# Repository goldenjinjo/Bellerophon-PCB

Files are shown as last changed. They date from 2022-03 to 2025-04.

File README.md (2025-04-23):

# hardware
Pronounced: BE-LLER-O-FIN

Pyro-capable Flight Computer with a pressure sensor and IMU. Designed to be general purpose and small enough to fit inside any rocket. Originally developed for UNSW Rocketry Team. 

**PARTS LIST:**

- Microprocessor: Teensy 4
- Barometer/Altimeter: MPL3115A2
- Inertial Measurement Unit (IMU): LSM6DS3
- Memory: XTSD 4GB NAND Flash
- Secondary IMU (optional): Adafruit ICM20948 Breakout Board
- PWM Buzzer
- Individual R, G, B Leds + dedicated programmable LEDs for Barometer, IMU and Flash

---

## 📸 Overview

### 📐 PCB Layout

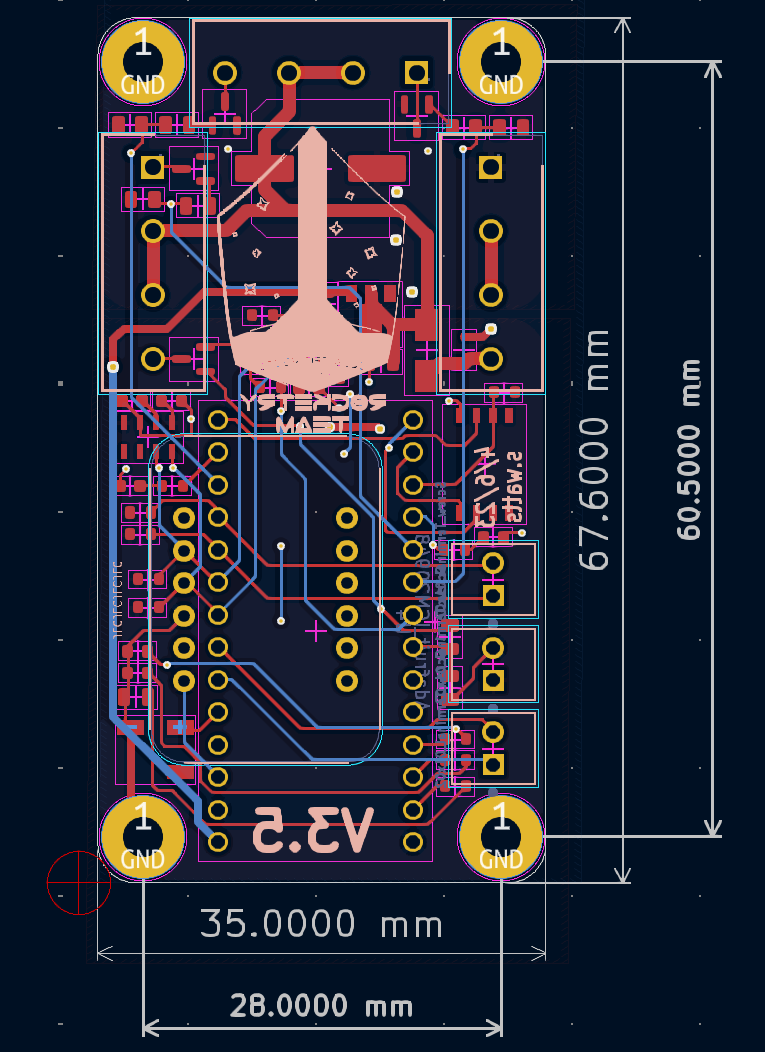
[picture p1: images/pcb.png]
PCB Layout


**Dimensions**: 35.0 mm × 67.6 mm  
**Mounting Holes**: ⌀3.2 mm (4-cornered)

---

### 🔧 Render – Back Side (Component View)

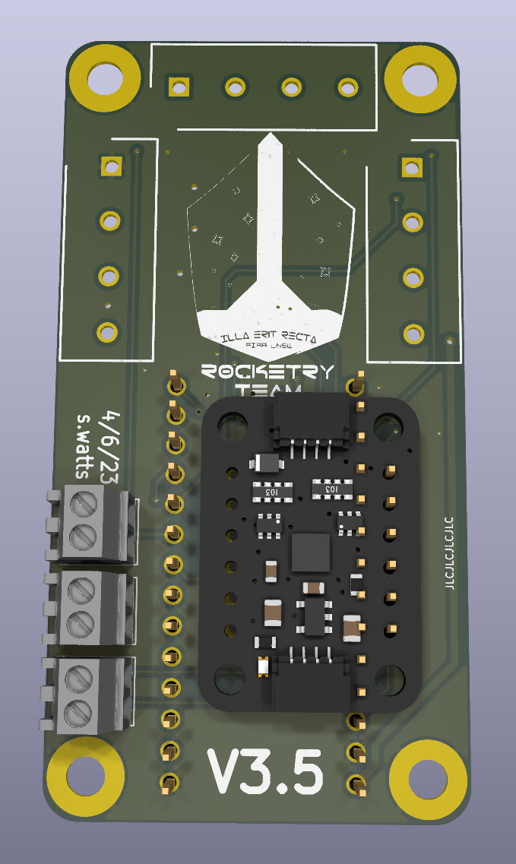
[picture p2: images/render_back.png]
Back Render


---

### ⚙️ Render – Front Side (Sensor & Output Side)

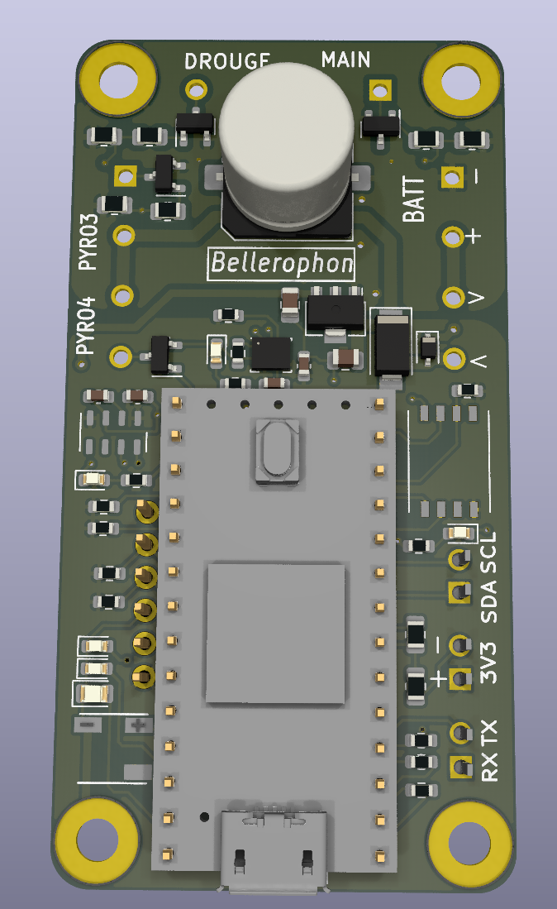
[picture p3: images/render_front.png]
Front Render


---

## 📊 Schematic

Schematic

Includes overcurrent protection, sensor routing, pyro switching, and regulator design for 3.3V and 5V rails.

---

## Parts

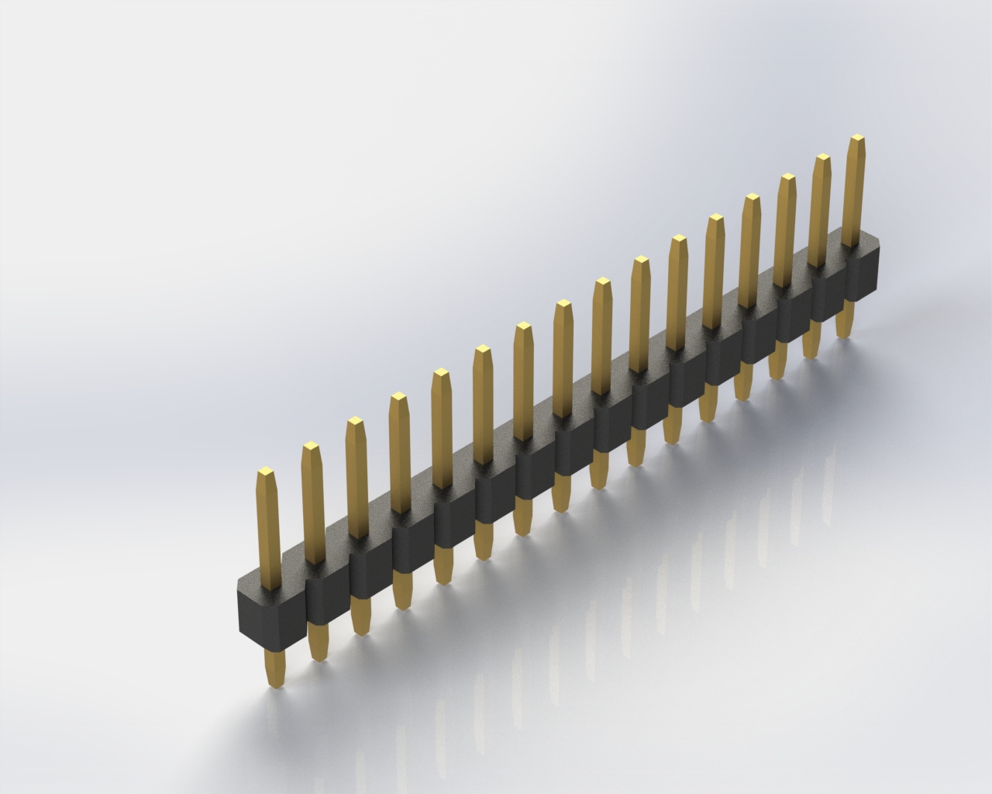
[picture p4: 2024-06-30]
bellerophon/component_libraries/3D_models/headers-2-54mm-1.snapshot.13/Header, Male, 2.54mm, 1x16.JPG

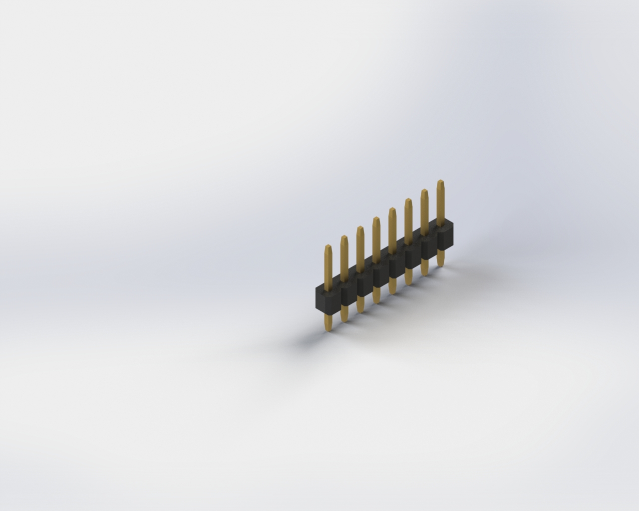
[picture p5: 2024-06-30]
bellerophon/component_libraries/3D_models/headers-2-54mm-1.snapshot.13/Header, Male, 2.54mm, 1x8.JPG

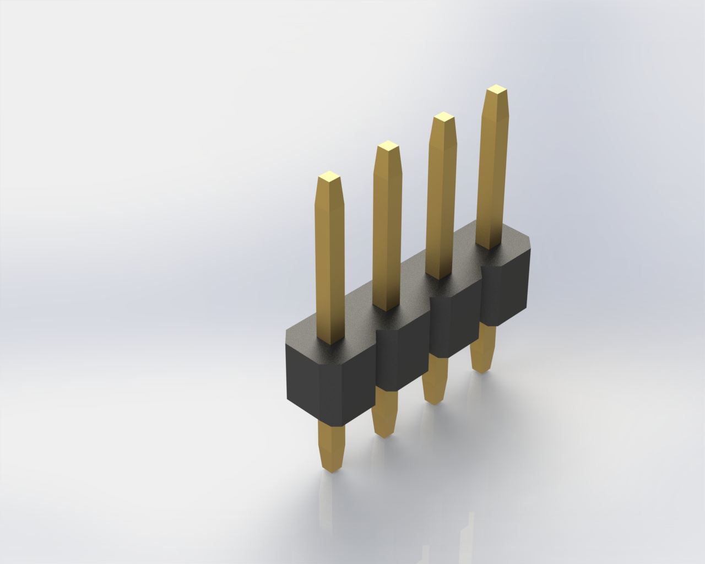
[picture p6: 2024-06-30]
bellerophon/component_libraries/3D_models/headers-2-54mm-1.snapshot.13/Header, Male, 2.54mm, 1x4.JPG

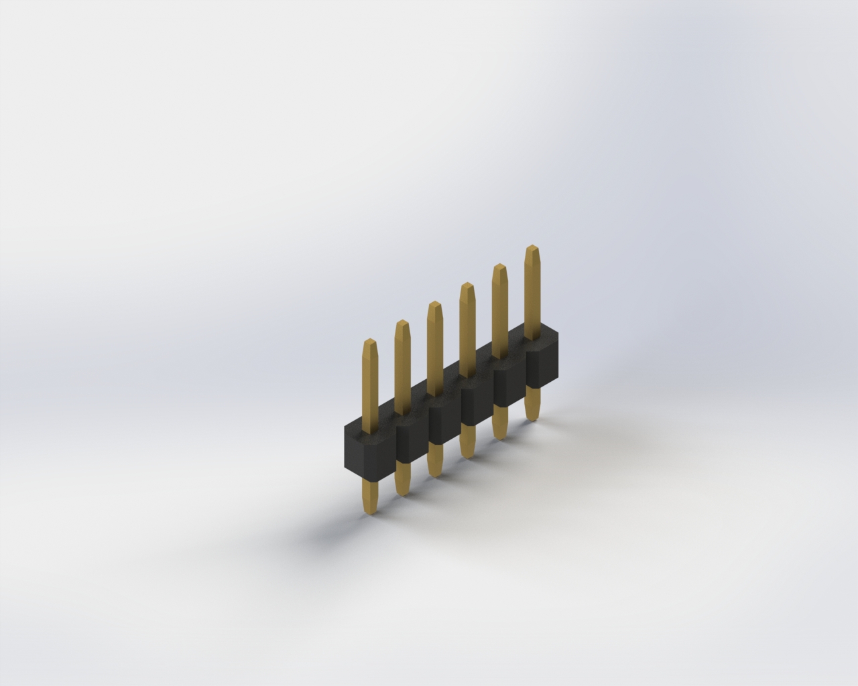
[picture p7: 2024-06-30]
bellerophon/component_libraries/3D_models/headers-2-54mm-1.snapshot.13/Header, Male, 2.54mm, 1x6.JPG

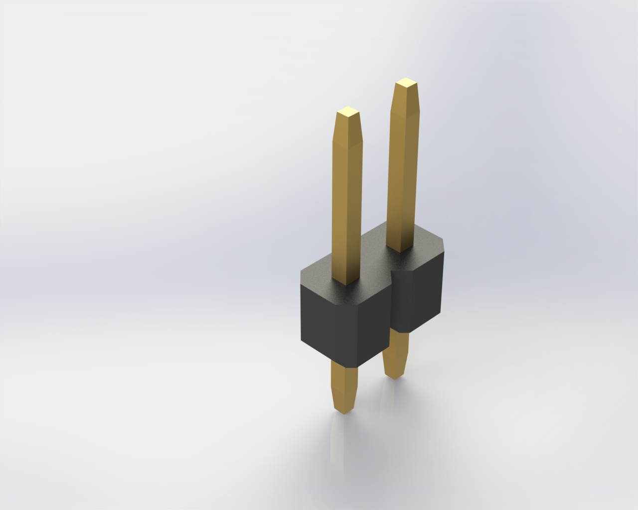
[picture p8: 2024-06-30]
bellerophon/component_libraries/3D_models/headers-2-54mm-1.snapshot.13/Header, Male, 2.54mm, 1x2.JPG

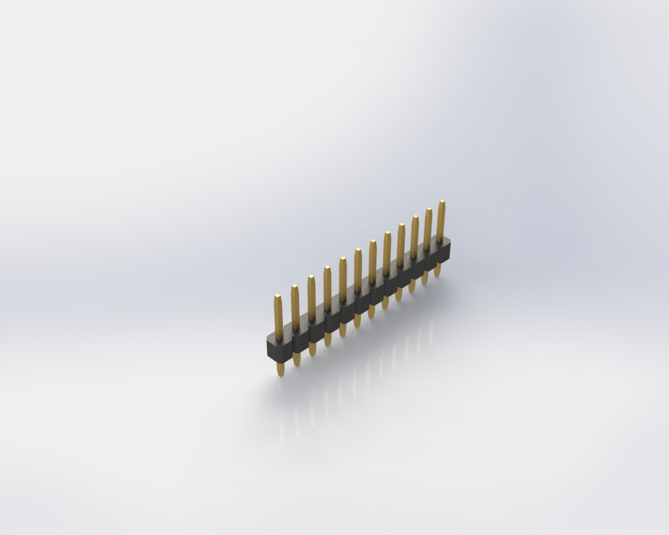
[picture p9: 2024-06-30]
bellerophon/component_libraries/3D_models/headers-2-54mm-1.snapshot.13/Header, Male, 2.54mm, 1x12.JPG

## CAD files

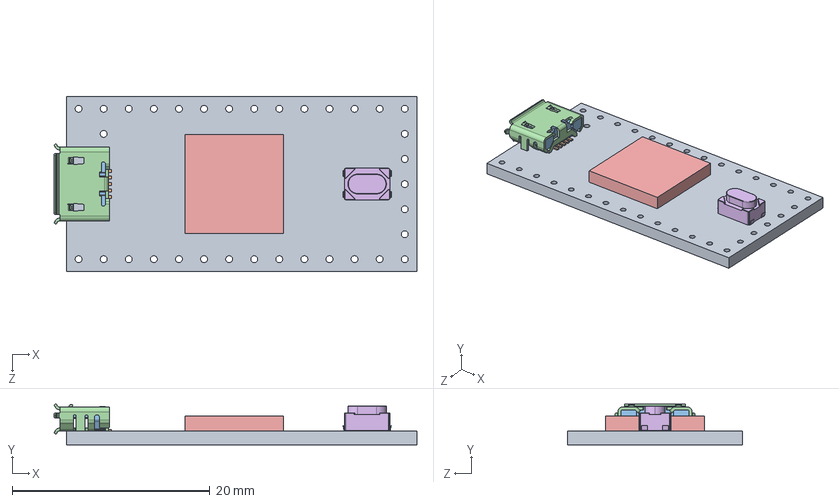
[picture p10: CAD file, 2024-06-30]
bellerophon/component_libraries/teensy_library-master/Teensy_4.0_Assembly.STEP
36.8 x 4.12 x 17.7 mm
Teensy_4.0_PCB
Micro USB-B Female 5Pin SMD
NXP iMXRT1062
SKRPACE010 v4

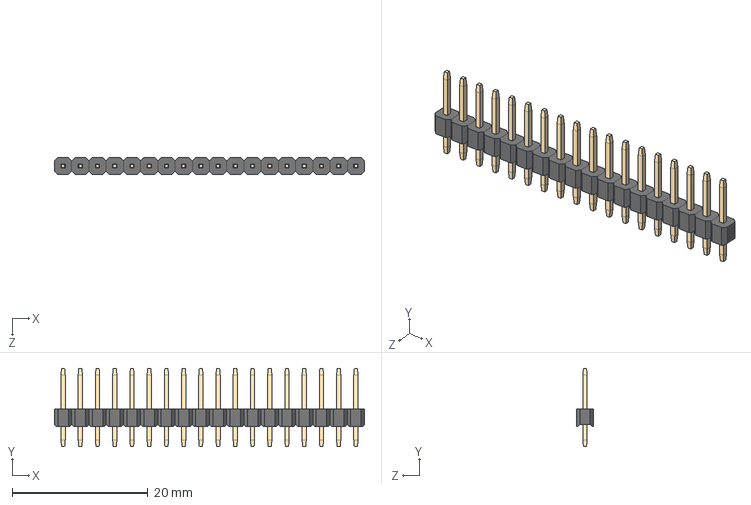
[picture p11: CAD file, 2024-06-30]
bellerophon/component_libraries/3D_models/headers-2-54mm-1.snapshot.13/Header, Male, 2.54mm, 1x18.STEP
45.7 x 11.5 x 2.54 mm

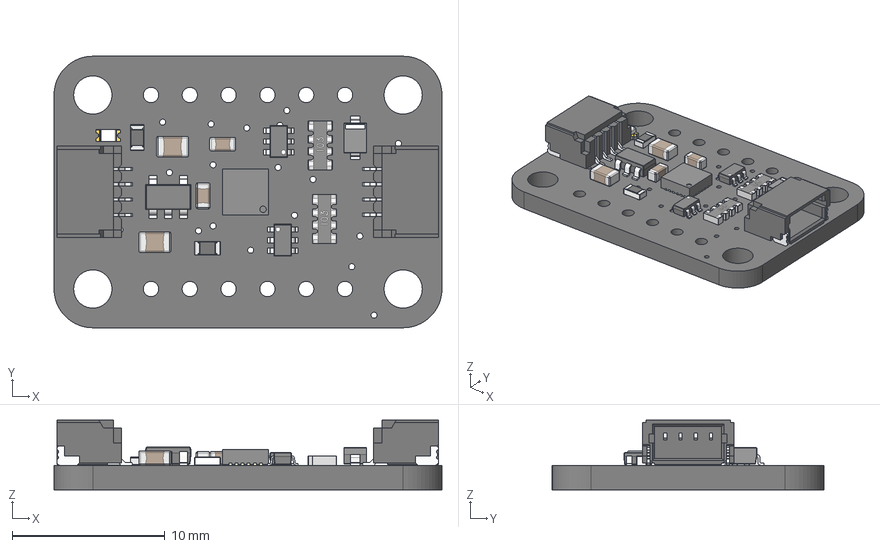
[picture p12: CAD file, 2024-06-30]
bellerophon/component_libraries/Adafruit/Adafruit ICM20948 STEMMA QT.step
25.4 x 17.8 x 4.55 mm
Printed Circuit Board
ICM-20948-9axis-IMU
SOT23-5
SOT23-6 x 2
LED 0603 single color
Cathode
Anode
Cathode Bar
CAPC-0603-T0.9-BN x 2
CAPC-0805-T0.95-BN x 2
RESC-0603 x 2
YC164_RESPACK x 2
qwicc x 2

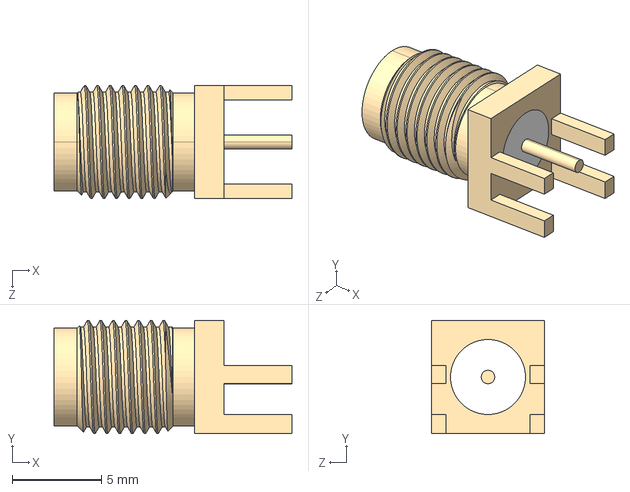
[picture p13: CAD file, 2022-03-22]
bellerophon/component_libraries/SMA-Connectors/CON-SMA-EDGE-S.step
13.3 x 6.35 x 6.35 mm

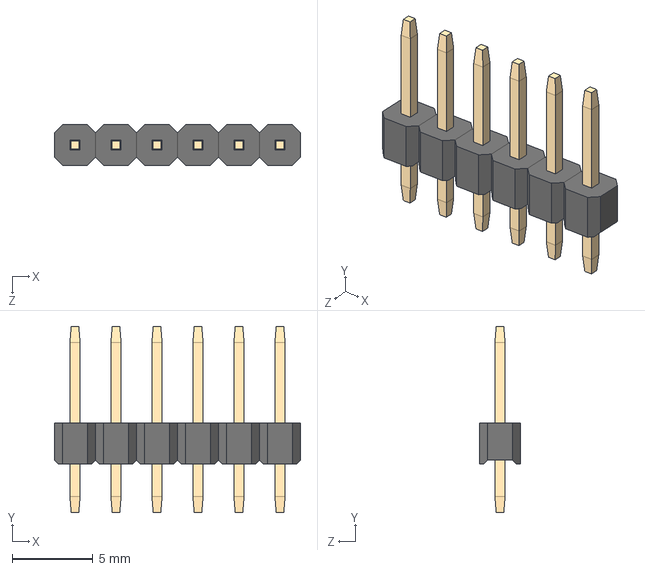
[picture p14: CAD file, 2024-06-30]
bellerophon/component_libraries/3D_models/headers-2-54mm-1.snapshot.13/Header, Male, 2.54mm, 1x6.STEP
15.2 x 11.5 x 2.54 mm

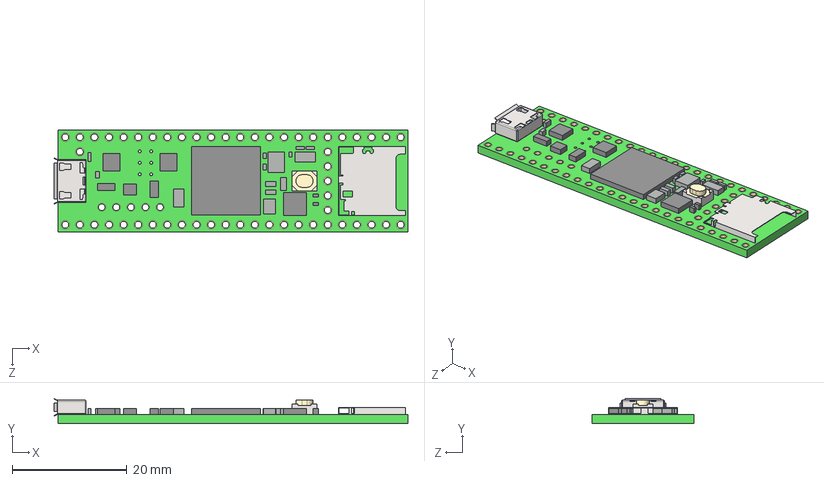
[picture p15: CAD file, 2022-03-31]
bellerophon/component_libraries/teensy_library-master/TEENSY_4.1.stp
61.7 x 4.35 x 17.8 mm

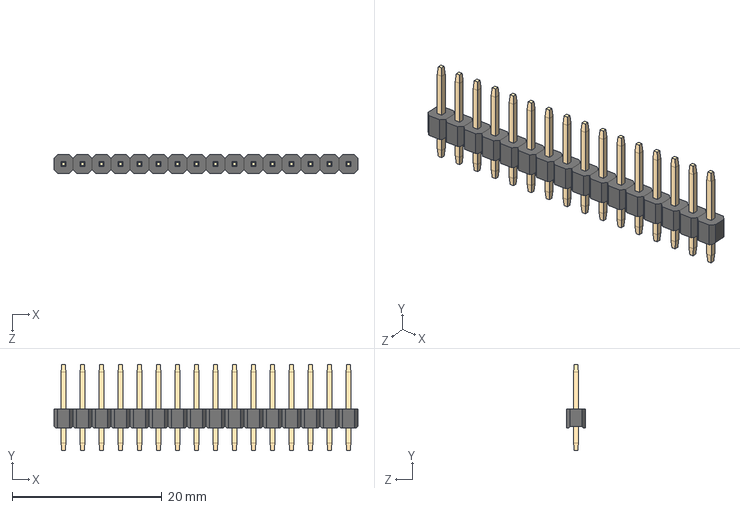
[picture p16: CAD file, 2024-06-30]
bellerophon/component_libraries/3D_models/headers-2-54mm-1.snapshot.13/Header, Male, 2.54mm, 1x16.STEP
40.6 x 11.5 x 2.54 mm

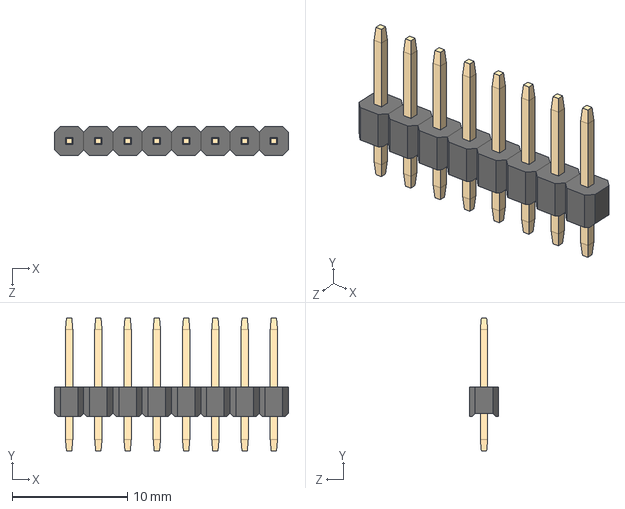
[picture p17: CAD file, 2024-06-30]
bellerophon/component_libraries/3D_models/headers-2-54mm-1.snapshot.13/Header, Male, 2.54mm, 1x8.STEP
20.3 x 11.5 x 2.54 mm

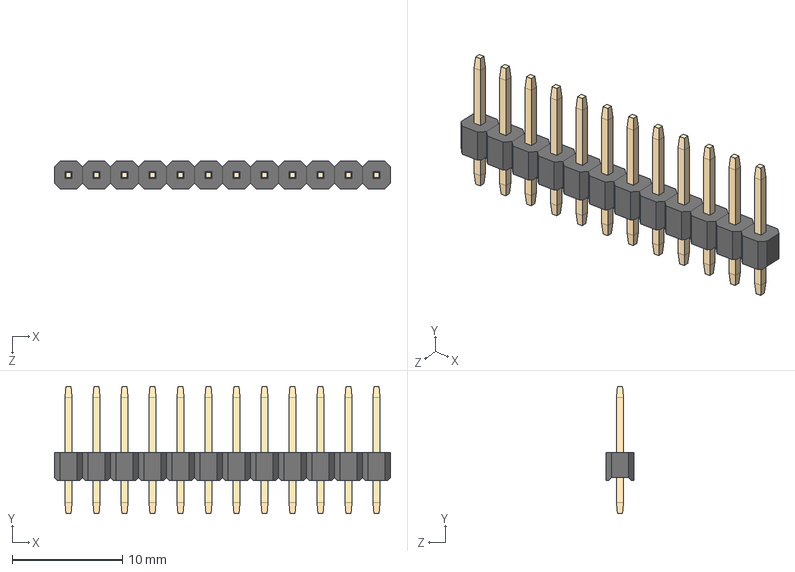
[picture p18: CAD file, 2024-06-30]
bellerophon/component_libraries/3D_models/headers-2-54mm-1.snapshot.13/Header, Male, 2.54mm, 1x12.STEP
30.5 x 11.5 x 2.54 mm

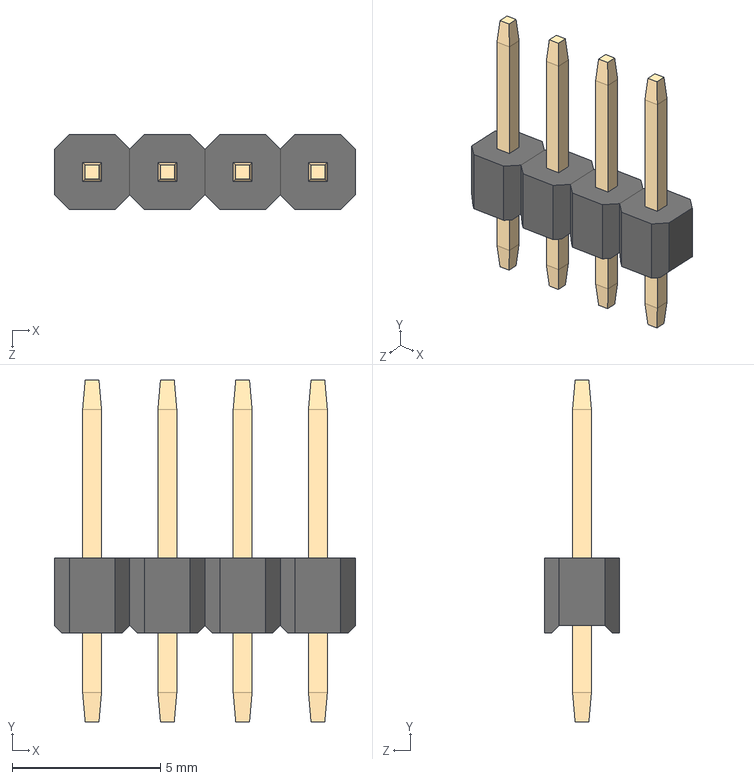
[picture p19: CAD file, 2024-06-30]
bellerophon/component_libraries/3D_models/headers-2-54mm-1.snapshot.13/Header, Male, 2.54mm, 1x4.STEP
10.2 x 11.5 x 2.54 mm

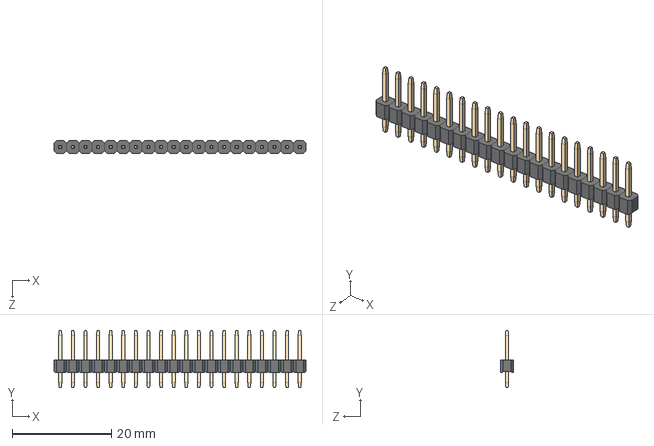
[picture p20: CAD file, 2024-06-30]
bellerophon/component_libraries/3D_models/headers-2-54mm-1.snapshot.13/Header, Male, 2.54mm, 1x20.STEP
50.8 x 11.5 x 2.54 mm

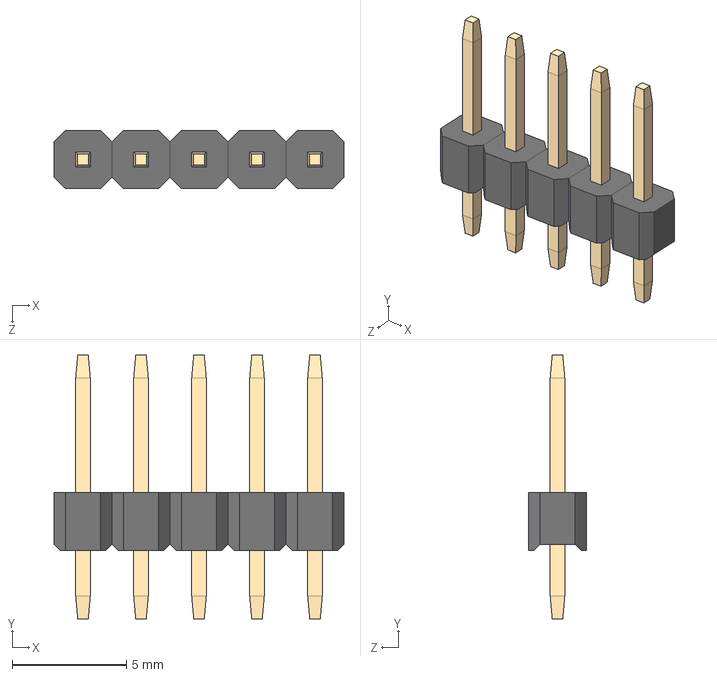
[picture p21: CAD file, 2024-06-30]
bellerophon/component_libraries/3D_models/headers-2-54mm-1.snapshot.13/Header, Male, 2.54mm, 1x5.STEP
12.7 x 11.5 x 2.54 mm

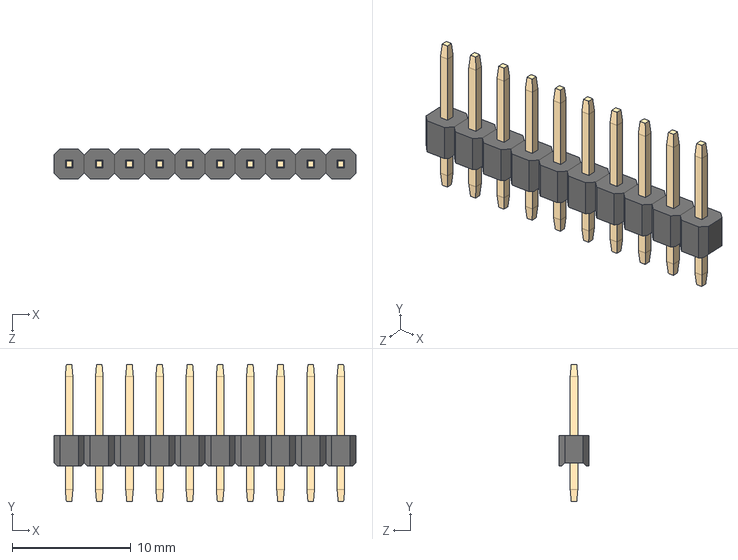
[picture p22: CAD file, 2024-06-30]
bellerophon/component_libraries/3D_models/headers-2-54mm-1.snapshot.13/Header, Male, 2.54mm, 1x10.STEP
25.4 x 11.5 x 2.54 mm

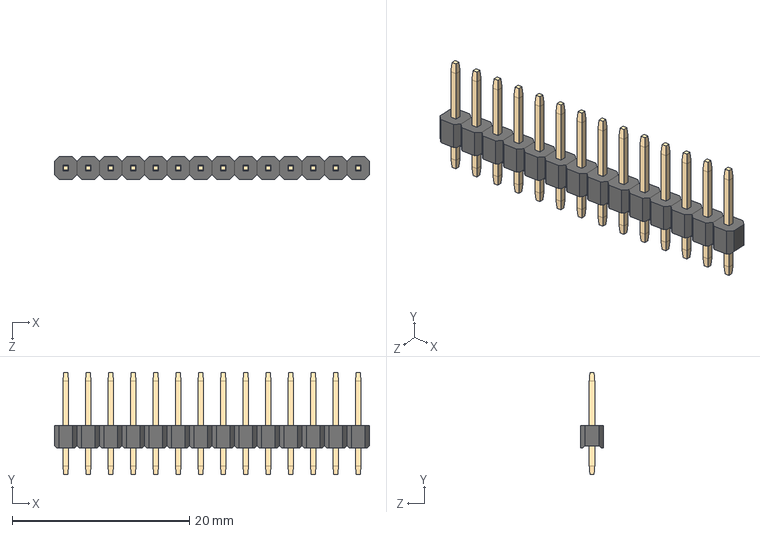
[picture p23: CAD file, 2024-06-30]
bellerophon/component_libraries/3D_models/headers-2-54mm-1.snapshot.13/Header, Male, 2.54mm, 1x14.STEP
35.6 x 11.5 x 2.54 mm

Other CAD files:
bellerophon/component_libraries/3D_models/headers-2-54mm-1.snapshot.13/Header, Male, 2.54mm, 1x3.STEP
bellerophon/component_libraries/3D_models/headers-2-54mm-1.snapshot.13/Header, Male, 2.54mm, 1x2.STEP

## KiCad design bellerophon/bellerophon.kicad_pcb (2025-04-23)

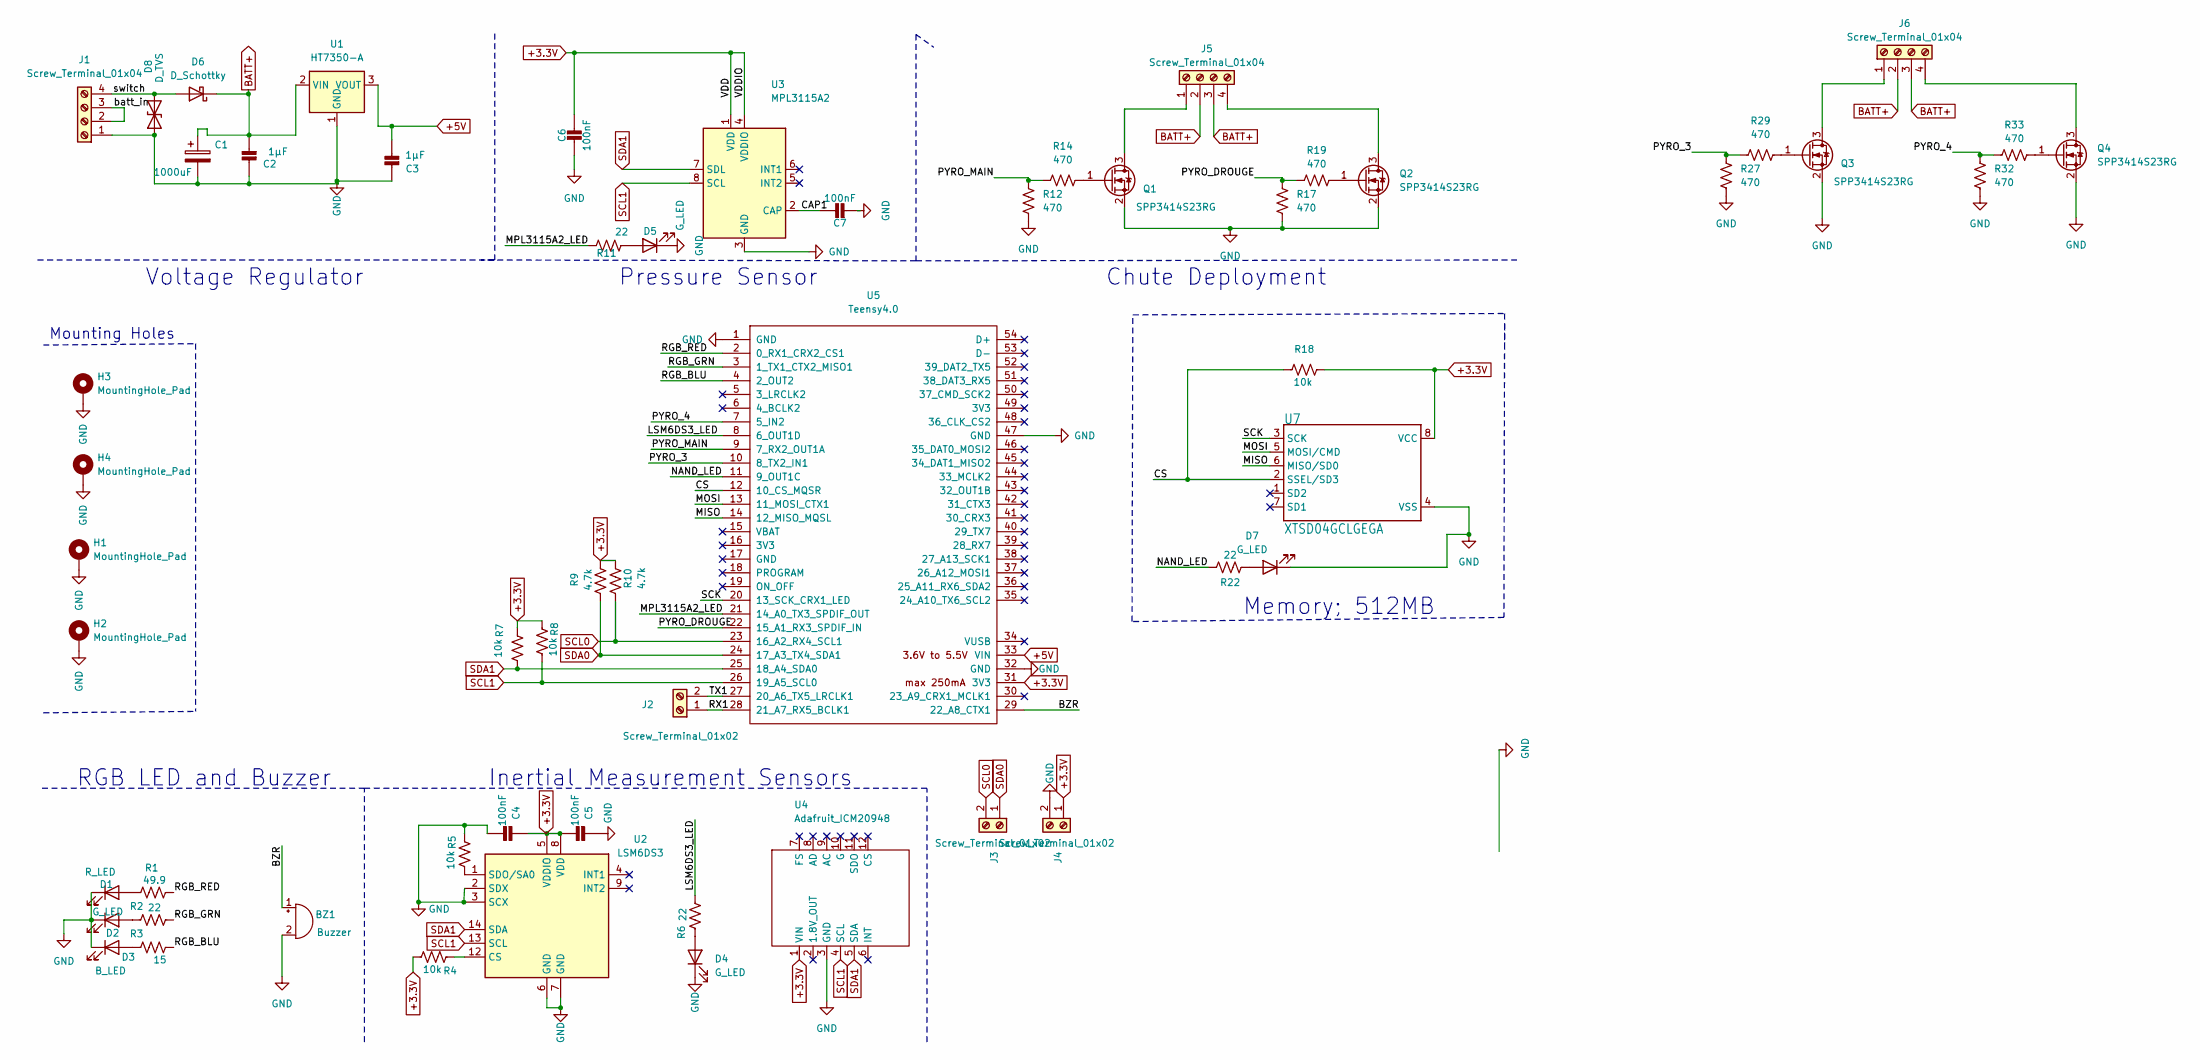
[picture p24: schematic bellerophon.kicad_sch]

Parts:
BZ1: Buzzer; YUEXIN YX-SMD5020; LCSC C781883
C1: 1000uF; C_Elec_10x10.2; LCSC C280408
C2, C3: 1µF; C_0805_2012Metric; LCSC C28323
C4, C5, C6, C7: 100nF; C_0603_1608Metric; LCSC C14663
D1: R_LED; LED_0805_2012Metric; LCSC C84256
D2, D4, D5, D7: G_LED; LED_0603_1608Metric; LCSC C72043
D3: B_LED; LED_0603_1608Metric; LCSC C72041
D6: D_Schottky; D_SMA; LCSC Part C22452
D8: D_TVS; D_SOD-323; LCSC Part C127529
H1, H2, H3, H4: MountingHole_Pad; MountingHole_3.2mm_M3_Pad
J1, J5, J6: Screw_Terminal_01x04; SHDR4W100P0X500_1X4_2000X800X1000P
J2, J3, J4: Screw_Terminal_01x02; CONN_282834-2
Q1, Q2, Q3, Q4: SPP3414S23RG; SOT-23; LCSC C114458
R1: 49.9; R_0603_1608Metric; LCSC C23185
R2, R6, R11, R22: 22; R_0603_1608Metric; LCSC C23345
R3: 15; R_0603_1608Metric; LCSC C22810
R4, R5, R7, R8, R18: 10k; R_0603_1608Metric; LCSC C25804
R9, R10: 4.7k; R_0603_1608Metric; LCSC C17673
R12, R14, R19, R27, R29, R32, R33: 470; R_0805_2012Metric; LCSC C17710
R17: 470; R_0805_2012Metric; LCSC C23179
U1: HT7350-A; SOT-89-3; LCSC C7874
U2: LSM6DS3; LGA-14_3x2.5mm_P0.5mm_LayoutBorder3x4y; LCSC C126672
U3: MPL3115A2; NXP_LGA-8_3x5mm_P1.25mm_H1.1mm; LCSC C54429
U4: Adafruit_ICM20948; ICM20946-B25.4x17.78mm-2X06_ROUND-P2.54mm
U5: Teensy4.0; Teensy40
U7: XTSD04GCLGEGA; LGA8_8X6; LCSC C2759953

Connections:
+3.3V: C4.1, C5.2, C6.1, J4.1, R4.2, R7.1, R8.1, R9.2, R10.2, R18.1, U2.5 (VDDIO), U2.8 (VDD), U3.1 (VDD), U3.4 (VDDIO), U4.1 (VIN), U5.31 (3V3), U7.8 (VCC)
+5V: C3.2, U1.3 (VOUT), U5.33 (VIN)
/BZR: BZ1.1 (-), U5.29 (22_A8_CTX1)
/CAP1: C7.1, U3.2 (CAP)
/CS: R18.2, U5.12 (10_CS_MQSR), U7.2 (SSEL/SD3)
/LSM6DS3_LED: R6.2, U5.8 (6_OUT1D)
/MISO: U5.14 (12_MISO_MQSL), U7.6 (MISO/SD0)
/MOSI: U5.13 (11_MOSI_CTX1), U7.5 (MOSI/CMD)
/MPL3115A2_LED: R11.1, U5.21 (14_A0_TX3_SPDIF_OUT)
/NAND_LED: R22.1, U5.11 (9_OUT1C)
/PYRO_3: R27.2, R29.1, U5.10 (8_TX2_IN1)
/PYRO_4: R32.2, R33.1, U5.7 (5_IN2)
/PYRO_DROUGE: R17.2, R19.1, U5.22 (15_A1_RX3_SPDIF_IN)
/PYRO_MAIN: R12.2, R14.1, U5.9 (7_RX2_OUT1A)
/RGB_BLU: R3.2, U5.4 (2_OUT2)
/RGB_GRN: R2.2, U5.3 (1_TX1_CTX2_MISO1)
/RGB_RED: R1.2, U5.2 (0_RX1_CRX2_CS1)
/RX1: J2.1, U5.28 (21_A7_RX5_BCLK1)
/SCK: U5.20 (13_SCK_CRX1_LED), U7.3 (SCK)
/TX1: J2.2, U5.27 (20_A6_TX5_LRCLK1)
/batt_in: J1.2, J1.3
/switch: D6.2 (A), D8.2 (A2), J1.4
BATT+: C1.1, C2.2, D6.1 (K), J5.2, J5.3, J6.2, J6.3, U1.2 (VIN)
GND: BZ1.2 (+), C1.2, C2.1, C3.1, C4.2, C5.1, C6.2, C7.2, D1.1 (K), D2.1 (K), D3.1 (K), D4.1 (K), D5.1 (K), D7.1 (K), D8.1 (A1), H1.1, H2.1, H3.1, H4.1, J1.1, J4.2, Q1.2 (S), Q2.2 (S), Q3.2 (S), Q4.2 (S), R5.1, R12.1, R17.1, R27.1, R32.1, U1.1 (GND), U2.2 (SDX), U2.3 (SCX), U2.6 (GND), U2.7 (GND), U3.3 (GND), U4.3 (GND), U5.1 (GND), U5.32 (GND), U5.47 (GND), U7.4 (VSS)
unnamed: D1.2 (A), R1.1
unnamed: D2.2 (A), R2.1
unnamed: D3.2 (A), R3.1
unnamed: D7.2 (A), R22.2
unnamed: J5.1, Q1.3 (D)
unnamed: J5.4, Q2.3 (D)
unnamed: J6.1, Q3.3 (D)
unnamed: J6.4, Q4.3 (D)
unnamed: Q1.1 (G), R14.2
unnamed: Q2.1 (G), R19.2
unnamed: Q3.1 (G), R29.2
unnamed: Q4.1 (G), R33.2
unnamed: R4.1, U2.12 (CS)
unnamed: R5.2, U2.1 (SDO/SA0)
unnamed: D4.2 (A), R6.1
unnamed: D5.2 (A), R11.2
SCL0: J3.2, R10.1, U5.23 (16_A2_RX4_SCL1)
SCL1: R8.2, U2.13 (SCL), U3.8 (SCL), U4.4 (SCL), U5.26 (19_A5_SCL0)
SDA0: J3.1, R9.1, U5.24 (17_A3_TX4_SDA1)
SDA1: R7.2, U2.14 (SDA), U3.7 (SDL), U4.5 (SDA), U5.25 (18_A4_SDA0)

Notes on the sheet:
Chute Deployment
Memory; 512MB
Mounting Holes
RGB LED and Buzzer
Pressure Sensor
Voltage Regulator
Inertial Measurement Sensors

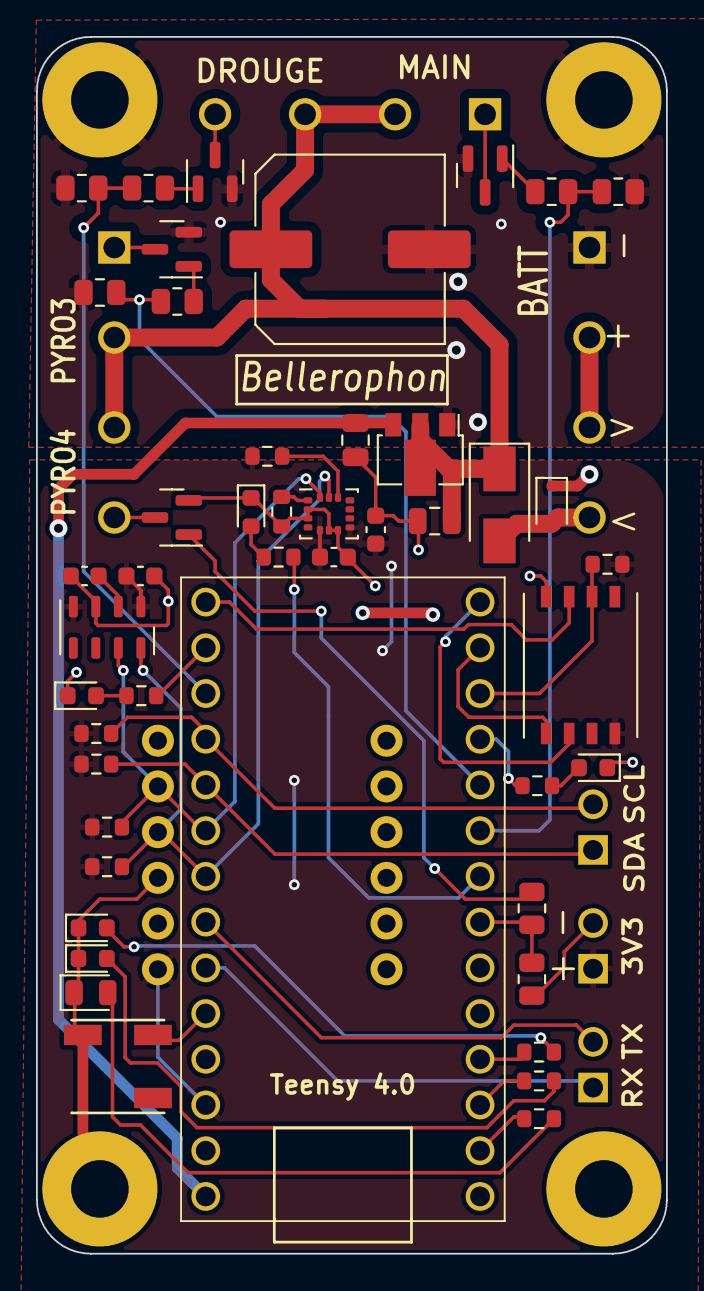
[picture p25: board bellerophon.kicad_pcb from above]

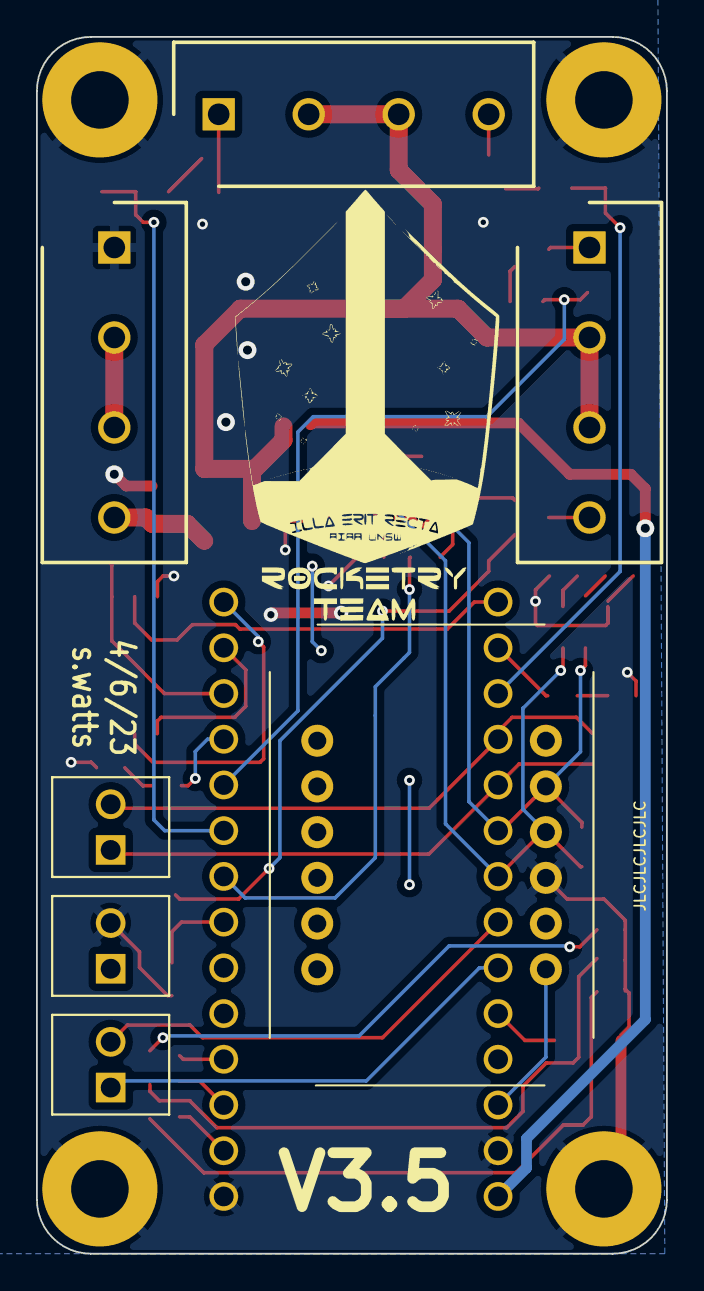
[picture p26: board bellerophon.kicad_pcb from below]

Board: 2 copper layers, 35.0 x 67.6 mm, 57 parts (7 on the bottom side), 44 nets.

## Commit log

2022-02-04 Add files via upload
    Completed footprints and symbols for all sensors in first iteration, first revision of schematic
    [pegasus.kicad_pcb, pegasus.kicad_sch]
2022-02-25 Added more components and attached footprints
    added voltage regulator for rfd900, battery connectors and updated footprints for all components.
    [pegasus.kicad_sch]
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2022-02-25 outlined approximate geometry of pcb and made some connections
    [pegasus.kicad_pcb, pegasus.kicad_sch]
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2022-03-22 removed one of connectors, fixed connector schematic wiring
    [pegasus.kicad_pcb, pegasus.kicad_sch]
2022-03-22 created sma-connector schematic and footprint and implemented 3D step file
    [pegasus.kicad_pcb, pegasus.kicad_sch]
2022-03-23 fixed UART wiring for gps and modem
    [pegasus.kicad_pcb, pegasus.kicad_sch]
2022-03-23 finalized board dimensions (50x120mm) and component positioning. completed draft of traces
    [pegasus.kicad_pcb, pegasus.kicad_sch]
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2022-03-31 added ground plane and vias. completed trace routing
    [pegasus.kicad_pcb]
2022-03-31 adjusted trace width for 5V power, added mounting holes, some 3D models
    [pegasus.kicad_pcb, pegasus.kicad_sch]
2022-03-31 added logo and cleaned up some silkscreens on PCB
    [pegasus.kicad_pcb]
2022-03-31 extended ground plane to edge of board, created 3mm fillet for ground plane
    [pegasus.kicad_pcb]
2022-03-31 added no connection flag to schematics, fixed minor mistakes on PCB and in footprints
    [pegasus.kicad_pcb, pegasus.kicad_sch]
2022-03-31 fixed BNO055 pin numbering, cleaned up schematic
    [pegasus.kicad_pcb, pegasus.kicad_sch]
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2022-04-06 added chute deployment mosfets
    added chute deployment mosfets
    [bellerophon.kicad_sch]
2022-04-07 Revert "added MPL3115A2 to Bellephrone Schematic"
    [bellerophon.kicad_sch]
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2022-04-07 LED/Buzzer circuits added to bellerophon schematic
    [bellerophon.kicad_sch]
2022-04-08 PaulBess: added drawing for Adafruit MPL3115A2, goldenjinjo: changed chute deployment resistors to 5 ohms
    [bellerophon.kicad_sch]
2022-04-08 fixed misalignment on SD chip symbol; added SD chip drawing to schematic
    [bellerophon.kicad_sch]
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2022-04-10 Add Adafruit ICM20948 footprint to adafruit library. Also add Adafruit ICM20948 wiring to the schematics file
    [bellerophon.kicad_sch]
2022-04-10 fix fab name text on footprint, change ICM wiring to SDA0, SCL0 pins
    [bellerophon.kicad_sch]
2022-04-14 Update bellerophon.kicad_sch
    updated screw terminal. footprints are ok for the mosfets T-220 form. 5W Resistor through hole assumed a distance of 10mm or so between holes (looks like a big resistor 25mm long about 7mm wide. Unkn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
    [bellerophon.kicad_sch]
2022-04-15 LED and Buzzer footprints added
    [bellerophon.kicad_sch]
2022-04-18 Update the schematic of the voltage regulator. Add the footprint of the switching diode.
    [bellerophon.kicad_sch]
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2022-04-18 add voltage regulator and teensy footprint libraries and assign footprints to symbols in schematic
    [bellerophon.kicad_sch]
2022-04-18 add terminal block footprints to schematic and update pcbnew
    [bellerophon.kicad_pcb, bellerophon.kicad_sch]
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2022-04-20 change teensy footprint to THT, change some resistors, layed out components and boardcut in pcbnew
    [bellerophon.kicad_pcb, bellerophon.kicad_sch]
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2022-04-22 add second buzzer
    [bellerophon.kicad_pcb, bellerophon.kicad_sch]
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2022-04-22 curved board edges and reduced height to 98 mm
    [bellerophon.kicad_pcb]
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2022-04-22 change capacitor to rectangle footprint, add remaining silkscreens
    [bellerophon.kicad_pcb, bellerophon.kicad_sch]
2022-04-22 add silkscreen to missing sides of ICM20948, SPI-Flash, and MPL3115A2
    [bellerophon.kicad_pcb]
2022-04-22 Update pinhole size in the diode footprint and update diode footprint in schematic
    [bellerophon.kicad_sch]
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2022-04-22 fix numbering error on diode footprint
    [bellerophon.kicad_pcb]
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2022-04-23 small modifications to PCB wiring and silkscreen positioning
    [bellerophon.kicad_pcb]
2022-04-23 move teensy 4.0 silkscreen off of copper wire
    [bellerophon.kicad_pcb]
2022-04-26 rewire pyro to source directly from battery, remove via, clean up tracks
    [bellerophon.kicad_pcb, bellerophon.kicad_sch]
2022-04-29 change battery traces from parrallel to series, increase spacing of some traces from through hole pins
    [bellerophon-B_Cu.gbr, bellerophon-B_Mask.gbr, bellerophon-B_Paste.gbr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]
2022-04-29 fix led symbol so GND is pin 2 and not pin 4
    [bellerophon.kicad_pcb, bellerophon.kicad_sch]
2022-04-29 add diode footprint and stp file, remove old gbr files
    [bellerophon-B_Cu.gbr, bellerophon-B_Mask.gbr, bellerophon-B_Paste.gbr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]
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2022-04-29 increase SPI flash footprint pin size to 1mm so it fits with standardized connectors
    [bellerophon.kicad_pcb]
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2022-05-04 Update bellerophon.kicad_sch
    Added surface mount resistors (1206 form) and surface mount Mosfet see links attached to the components for the ones to buy off RS components.
    Added a continuity check, this circuit is always live but draws a tiny current, it can be used to check the eMatch is present. A high signal of ~2.4-3V (via a voltage divider) depending on power source can be detected (should be above the logic high level of a teensy). and when 0V is detected then the pyro is either not connected OR it has been fired. DO NOT CONNECT A VOLTAGE SOURCE HIGHER THAN 10 VOLTS - This will result in a signal of >3.3 V and could damage teensy pins.
    Brown out capacitor wont be useful here I don'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
    [bellerophon.kicad_sch]
2022-05-04 Surface Mounts + Continuity
    Brown out capacitor wont be useful here I don't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
    [bellerophon.kicad_sch]
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2022-05-09 remove adafruit mpl3115a2 and replace with SMT circuit
    [bellerophon.kicad_pcb, bellerophon.kicad_sch]
2022-05-09 replace remaining resistors and capacitors with SMT components
    [bellerophon.kicad_pcb, bellerophon.kicad_sch]
2022-05-12 fix overlapping vias, move pyro resistor silkscreen
    [bellerophon.kicad_pcb]
2022-05-12 add missing breakout board files
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2022-05-12 fix nested repo issue with breakout boards
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2022-05-12 return breakout board, fix error
    [Adafruit BNO055.kicad_pcb, Adafruit BNO055.kicad_sch, Adafruit SPI Flash SD Card.kicad_pcb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]
2022-05-12 replace THT voltage regulator with SMT, 750mA SOT-89-3
    [bellerophon.kicad_pcb, bellerophon.kicad_sch]
2022-05-12 remove second battery input, combine battery and switch terminals into a single 1x4 terminal
    [bellerophon.kicad_pcb, bellerophon.kicad_sch]
2022-05-12 replace switching diode with SMT PFET
    [bellerophon.kicad_pcb, bellerophon.kicad_sch]
2022-05-12 correct name on voltage regulator
    [bellerophon.kicad_sch]
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2022-05-23 remove second buzzer
    [bellerophon.kicad_pcb, bellerophon.kicad_sch]
2022-05-24 Replace ICM breakout board schematic with SMT BNO055 circuit
    [bellerophon.kicad_sch]
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2022-06-02 change buzzer pin to 14, rearange power circuitry
    [bellerophon.kicad_sch]
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2022-06-02 remove interupt, reboot and I2Caddress connection from BNO055
    [bellerophon.kicad_pcb, bellerophon.kicad_sch]
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2022-06-23 add missing connection of VDD to power (oops) and set reset pin to high
    [bellerophon.kicad_pcb, bellerophon.kicad_sch]
2022-06-25 simplify silkscreen of switch terminal, remove old step file. This is the version for production file V2.
    [bellerophon.kicad_pcb, bellerophon.step]
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2022-07-13 rename pyro and led pins to more useful names, change global labels in schematic to local
    [bellerophon.kicad_sch]
2022-07-13 replace pyro mosfets with correct symbol to fix the incorrect numbering of gate, source and drain.
    [bellerophon.kicad_pcb, bellerophon.kicad_sch]
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2023-02-06 add two more pyro channels, reduce screw terminal size, change buzzer, replace IMU with breakout board
    [bellerophon.kicad_pcb, bellerophon.kicad_sch]
2023-02-06 add smaller buzzer
    [bellerophon.kicad_pcb, bellerophon.kicad_sch]
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2023-02-09 add smaller GPIO connectors, add symbol for highG accelerometer, complete schematic design for 2/3 accelerometers
    [bellerophon.kicad_pcb, bellerophon.kicad_sch]
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2023-02-11 increase height, add anti brownout capacitor, add pinouts for pyros
    [bellerophon.kicad_pcb, bellerophon.kicad_sch]
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2023-02-16 replace RGB LED with 3 LEDs
    [bellerophon.kicad_pcb, bellerophon.kicad_sch, bellerophon.step]
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2023-02-17 make all SMD footprints on front layer, move screw terminals to bottom layer
    [bellerophon.kicad_pcb, bellerophon.kicad_sch]
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2023-02-17 fix uup edge cut, create gerbers
    [bellerophon.kicad_pcb]
2023-02-17 fix some lcsc part numbers and footprints
    [bellerophon.kicad_pcb, bellerophon.kicad_sch]
2023-02-17 update lcsc values to represent basic JLC parts rather than extextended. Change some footprints and reduce BATT trace width to 1.2mm
    [bellerophon.kicad_pcb, bellerophon.kicad_sch]
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2023-02-18 create temporary solution to display 4 pin screw terminal models, add mounting hole spacing dimensions
    [bellerophon.kicad_pcb]
2023-04-26 fix I2C0 wiring to wrong place on microcontroller
    [Adafruit ICM20948 STEMMA QT.step.SLDASM, C_0603_1608Metric.step.SLDASM, C_0805_2012Metric.step.SLDASM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]
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2023-04-27 replace power and pyro connectors with 5mm spacing
    [bellerophon.kicad_pcb, bellerophon.kicad_sch]
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2023-04-27 add reverse polarity protection
    [bellerophon.kicad_sch]
2023-06-04 clean up component placing, route new traces, add TVS diode for surge protection, combine sensor I2C into same pins
    [bellerophon.kicad_pcb, bellerophon.kicad_sch]
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2025-04-23 remove step files, manufacturing files, temp files, update gitignore for more temp files
    [Adafruit ICM20948 STEMMA QT.step.SLDASM, C_0603_1608Metric.step.SLDASM, C_0805_2012Metric.step.SLDASM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]
